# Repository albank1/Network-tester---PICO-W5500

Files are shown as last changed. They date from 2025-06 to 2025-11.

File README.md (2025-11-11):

# Network-tester---PICO-W5500



Small battery powered network tester using WIZnet W5500-EVB-Pico and 1.3" OLED Display HAT

This is a project to create a cheap pocket sized network tester to find if a port is live and has DHCP scope. This is an improvement of my previous arduino Network Tester. This has been very useful for the hospital environment I work in where network ports are unpatched regularly. Yes you can use a laptop to do this and more but this is pocket sized and about £20.

It uses a WIZnet W5500-EVB-Pico with a 1.3" OLED Waveshare Display HAT. To power a LIPO battery, a cheap LIPO charging board and a toggle switch are used. The code is in MicroPython and there is a 3D printerable enclosure.

Parts required:
1) WIZnet W5500-EVB-Pico with header (eg from PI Hut)
2) 1.3" OLED Display HAT for Raspberry Pi Pico (64×128) (eg 1.3 oLED Waveshare from PI Hut)
3) 3.7V 260mAh 601730 or 300mAh Lipo battery
4) TP4056 Lithium Battery Charging Board - Type C
5) A switch to turn off/on (Rocker Switch Control Micro 14mm Diameter)
The LIPO is connected to the TP4056 and the output connected via the switch to the VSYS and the ground connected directly.

I have had to cut the pin on the 1.3 OLED HAT as one of the buttons connects to pin 17 on the PICO but this is also used for the W5500. This was instead soldered to pin 15.







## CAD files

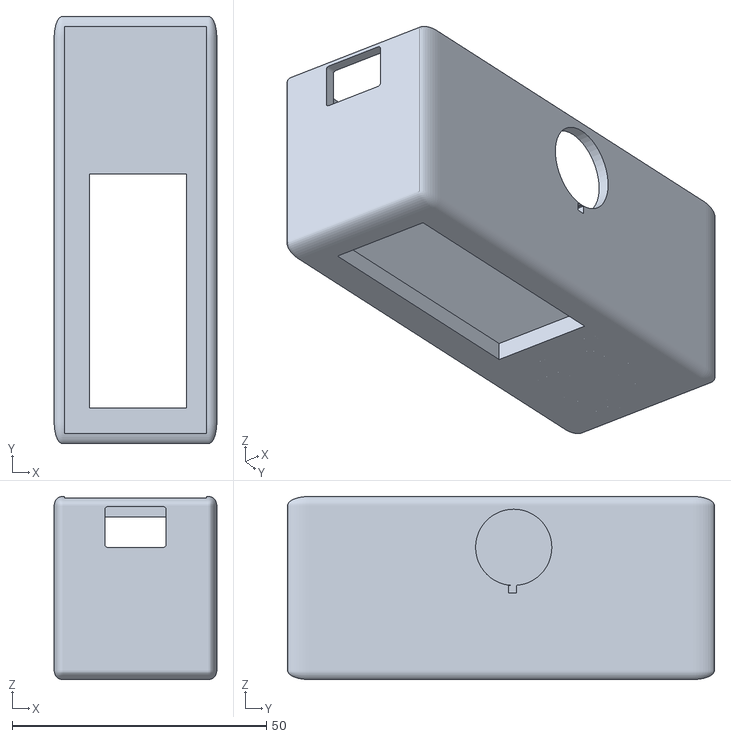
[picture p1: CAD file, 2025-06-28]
Ethernet Tester FINAL base.stl
32.0 x 84.0 x 36.0

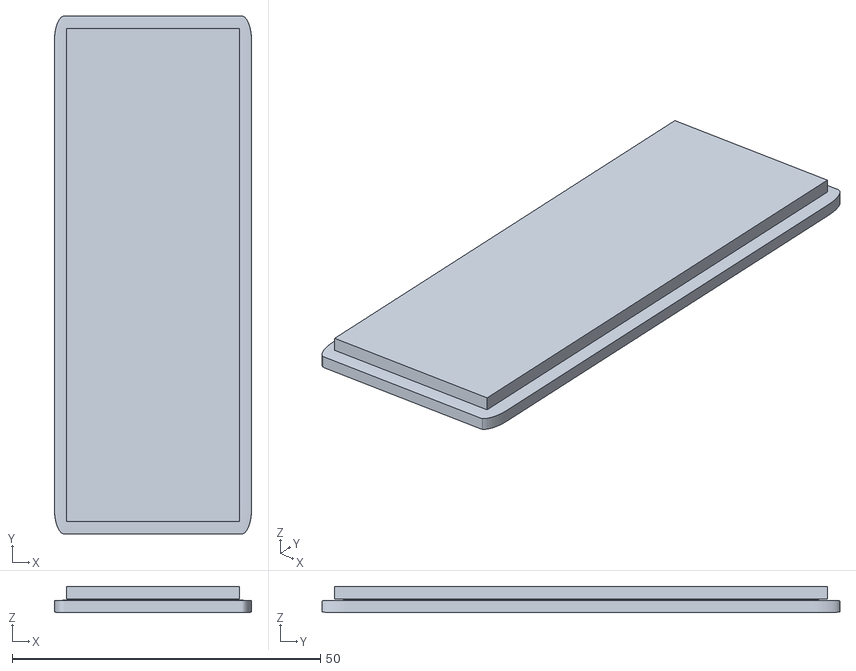
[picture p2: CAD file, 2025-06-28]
Ethernet Tester FINAL top.stl
32.0 x 84.0 x 4.24

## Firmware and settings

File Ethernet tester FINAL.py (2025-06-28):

# For WIZnet W5500-EVB-Pico2 with 1.3 OLED Waveshare hat

from usocket import socket, AF_INET, SOCK_DGRAM, getaddrinfo
from machine import Pin, SPI
import network
import framebuf
import time
import struct

# OLED pin config
DC = 8
RST = 12
MOSI = 11
SCK = 10
CS = 9

class OLED_1inch3(framebuf.FrameBuffer):
    def __init__(self):
        self.width = 128
        self.height = 64
        self.rotate = 180
        self.cs = Pin(CS, Pin.OUT)
        self.rst = Pin(RST, Pin.OUT)
        self.cs(1)
        self.spi = SPI(1, 20000000, polarity=0, phase=0, sck=Pin(SCK), mosi=Pin(MOSI), miso=None)
        self.dc = Pin(DC, Pin.OUT)
        self.dc(1)
        self.buffer = bytearray(self.height * self.width // 8)
        super().__init__(self.buffer, self.width, self.height, framebuf.MONO_HMSB)
        self.init_display()
        self.white = 0xffff
        self.black = 0x0000

    def write_cmd(self, cmd):
        self.cs(1)
        self.dc(0)
        self.cs(0)
        self.spi.write(bytearray([cmd]))
        self.cs(1)

    def write_data(self, buf):
        self.cs(1)
        self.dc(1)
        self.cs(0)
        self.spi.write(bytearray([buf]))
        self.cs(1)

    def init_display(self):
        self.rst(1)
        time.sleep(0.001)
        self.rst(0)
        time.sleep(0.01)
        self.rst(1)
        for cmd in [
            0xAE, 0x00, 0x10, 0xB0, 0xDC, 0x00, 0x81, 0x6F, 0x21,
            0xA1 if self.rotate == 180 else 0xA0, 0xC0, 0xA4, 0xA6,
            0xA8, 0x3F, 0xD3, 0x60, 0xD5, 0x41, 0xD9, 0x22, 0xDB,
            0x35, 0xAD, 0x8A, 0xAF
        ]:
            self.write_cmd(cmd)

    def show(self):
        self.write_cmd(0xB0)
        for page in range(0, 64):
            self.column = 63 - page if self.rotate == 0 else page
            self.write_cmd(0x00 + (self.column & 0x0f))
            self.write_cmd(0x10 + (self.column >> 4))
            for num in range(0, 16):
                self.write_data(self.buffer[page * 16 + num])

# Initialize WIZnet chip
def w5x00_init(OLED, timeout=10):
    spi = SPI(0, 2_000_000, mosi=Pin(19), miso=Pin(16), sck=Pin(18))
    OLED.fill(0)
    OLED.text('Connecting...', 1, 0, OLED.white)
    OLED.show()
    try:
        nic = network.WIZNET5K(spi, Pin(17), Pin(20))  # CS=GP17, RST=GP20
        nic.active(True)

        start_time = time.ticks_ms()
        while time.ticks_diff(time.ticks_ms(), start_time) < timeout * 1000:
            ip = nic.ifconfig()[0]
            if ip and ip != '0.0.0.0':
                break
            time.sleep(0.1)

        ip, mask, gw, dns = nic.ifconfig()
        OLED.fill(0)
        if ip != '0.0.0.0':
            print("Connected! IP config:", ip, mask, gw, dns)
            OLED.text('IP Address:', 1, 0, OLED.white)
            OLED.text(ip, 1, 10, OLED.white)
            OLED.text('Mask:', 1, 20, OLED.white)
            OLED.text(mask, 1, 30, OLED.white)
            OLED.text('Gateway:', 1, 40, OLED.white)
            OLED.text(gw, 1, 50, OLED.white)         
        else:
            OLED.text('No network', 1, 0, OLED.white)
        OLED.show()
        return nic
    except Exception as e:
        print("Init failed:", e)
        OLED.fill(0)
        OLED.text('Network error', 1, 0, OLED.white)
        OLED.text('No DHCP/IP', 1, 10, OLED.white)
        OLED.show()
        return None

# DNS resolve
def dns_request(nic, OLED):
    SERVER = 'www.google.co.uk'

    try:
        OLED.fill(0)
        OLED.text('DNS query...', 1, 0, OLED.white)
        OLED.text(SERVER, 1, 10, OLED.white)       
        OLED.show()

        addr = getaddrinfo(SERVER, 80)[0][-1]
        print(addr[0])
        OLED.text("DNS Resolved", 1, 30, OLED.white)
        OLED.text(addr[0], 1, 40, OLED.white)
        OLED.show()
    except Exception as e:
        print("DNS failed:", e)
        OLED.text('DNS resolution failed', 1, 30, OLED.white)
        OLED.text(str(e), 1, 40, OLED.white)
        OLED.show()

# Main
if __name__ == "__main__":
    OLED = OLED_1inch3()
    OLED.fill(0)
    OLED.text('Initialising...', 1, 0, OLED.white)
    OLED.show()

    nic = w5x00_init(OLED)

    keyA = Pin(14, Pin.IN, Pin.PULL_UP)  # For re-checking network
    keyB = Pin(15, Pin.IN, Pin.PULL_UP)  # For SNTP request

    while True:
        if keyA.value() == 0:
            time.sleep(0.05)
            if keyA.value() == 0:
                dns_request(nic, OLED)

        if keyB.value() == 0:
            time.sleep(0.05)
            if keyB.value() == 0:
                OLED.fill(0)
                OLED.text('Rechecking...', 1, 0, OLED.white)
                OLED.show()
                time.sleep(0.7)
                nic = w5x00_init(OLED)

        time.sleep(0.1)

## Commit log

2025-06-28 3D print files for case
    [Ethernet Tester FINAL base.stl, Ethernet Tester FINAL top.stl]
2025-11-11 Fix README to reference WIZnet W5500-EVB-Pico
